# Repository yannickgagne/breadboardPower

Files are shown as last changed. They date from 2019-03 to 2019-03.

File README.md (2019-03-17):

# breadboardPower
Breadboard Power Supply

Simple breadboard power supply with 3.3V, 5V and 12V ouput.

Can provide two different voltage at the same time to different rails.

I know it could have been way smaller with more SMD components but I wanted to use what I had on hand.

https://oshpark.com/shared_projects/d1cXCggO

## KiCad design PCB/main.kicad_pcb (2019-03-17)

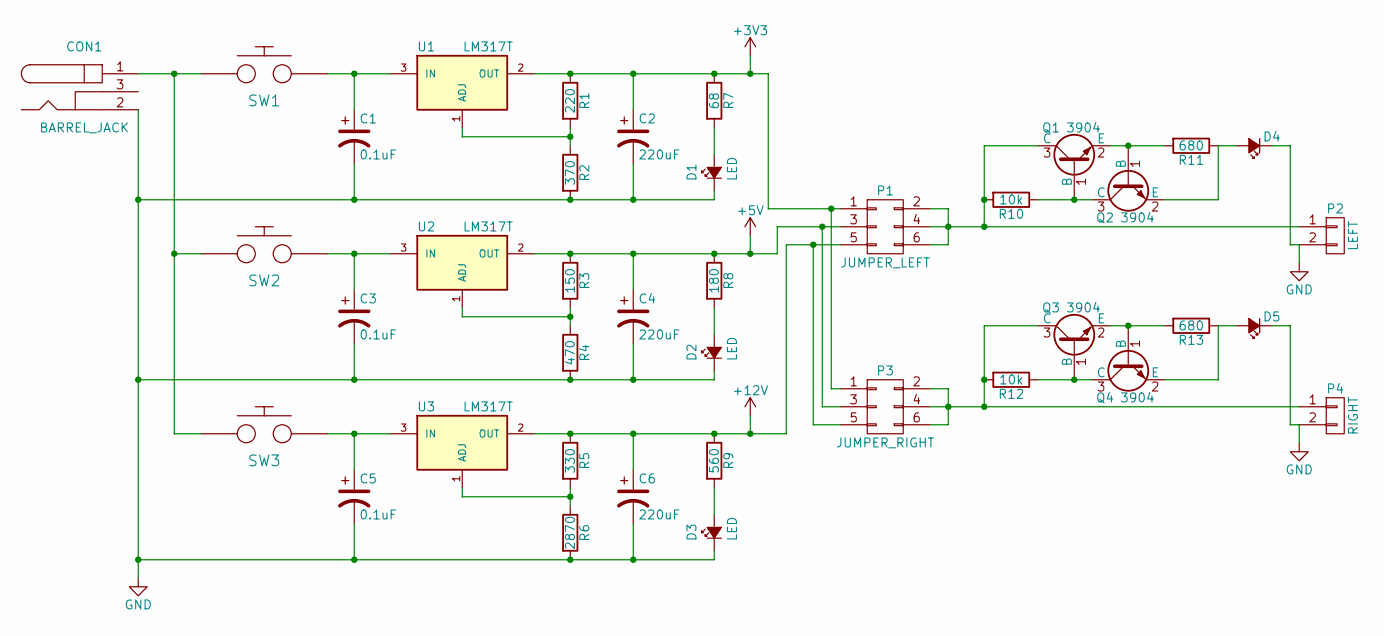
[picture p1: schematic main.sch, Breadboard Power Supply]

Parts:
C1, C3, C5: 0.1uF; C_Radial_D5_L11_P2
C2, C4, C6: 220uF; C_Radial_D6.3_L11.2_P2.5
CON1: BARREL_JACK; BARREL_JACK2
D1, D2, D3: LED; LED_0805
D4, D5: Led_Small; LED_0805
P1: JUMPER_LEFT; Pin_Header_Straight_2x03
P2: LEFT; Pin_Header_Straight_1x02
P3: JUMPER_RIGHT; Pin_Header_Straight_2x03
P4: RIGHT; Pin_Header_Straight_1x02
Q1, Q2, Q3, Q4: 3904; SOT-23
R1: 220; Resistor_Horizontal_RM7mm
R2: 370; Resistor_Horizontal_RM7mm
R3: 150; Resistor_Horizontal_RM7mm
R4: 470; Resistor_Horizontal_RM7mm
R5: 330; Resistor_Horizontal_RM7mm
R6: 2870; Resistor_Horizontal_RM7mm
R7: 68; Resistor_Horizontal_RM7mm
R8: 180; Resistor_Horizontal_RM7mm
R9: 560; Resistor_Horizontal_RM7mm
R10, R12: 10k; Resistor_Horizontal_RM7mm
R11, R13: 680; Resistor_Horizontal_RM7mm
SW1, SW2, SW3: 12x12_PUSHBUTTON_SPST
U1, U2, U3: LM317T; TO-220

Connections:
+3V3: C2.1, P1.1, P3.1, R1.1, R7.1, U1.2 (OUT)
+5V: C4.1, P1.3, P3.3, R3.1, R8.1, U2.2 (OUT)
+12V: C6.1, P1.5, P3.5, R5.1, R9.1, U3.2 (OUT)
GND: C1.2, C2.2, C3.2, C4.2, C5.2, C6.2, CON1.2, D1.1 (K), D2.1 (K), D3.1 (K), D4.1 (K), D5.1 (K), P2.2, P4.2, R2.2, R4.2, R6.2
unnamed: C1.1, SW1.2, U1.3 (IN)
unnamed: C3.1, SW2.2, U2.3 (IN)
unnamed: C5.1, SW3.2, U3.3 (IN)
unnamed: CON1.1, SW1.1, SW2.1, SW3.1
unnamed: D1.2 (A), R7.2
unnamed: D2.2 (A), R8.2
unnamed: D3.2 (A), R9.2
unnamed: D4.2 (A), Q2.2 (E), R11.1
unnamed: D5.2 (A), Q4.2 (E), R13.1
unnamed: P1.2, P1.4, P1.6, P2.1, Q1.3 (C), R10.2
unnamed: P3.2, P3.4, P3.6, P4.1, Q3.3 (C), R12.2
unnamed: Q1.1 (B), Q2.3 (C), R10.1
unnamed: Q1.2 (E), Q2.1 (B), R11.2
unnamed: Q3.1 (B), Q4.3 (C), R12.1
unnamed: Q3.2 (E), Q4.1 (B), R13.2
unnamed: R1.2, R2.1, U1.1 (ADJ)
unnamed: R3.2, R4.1, U2.1 (ADJ)
unnamed: R5.2, R6.1, U3.1 (ADJ)

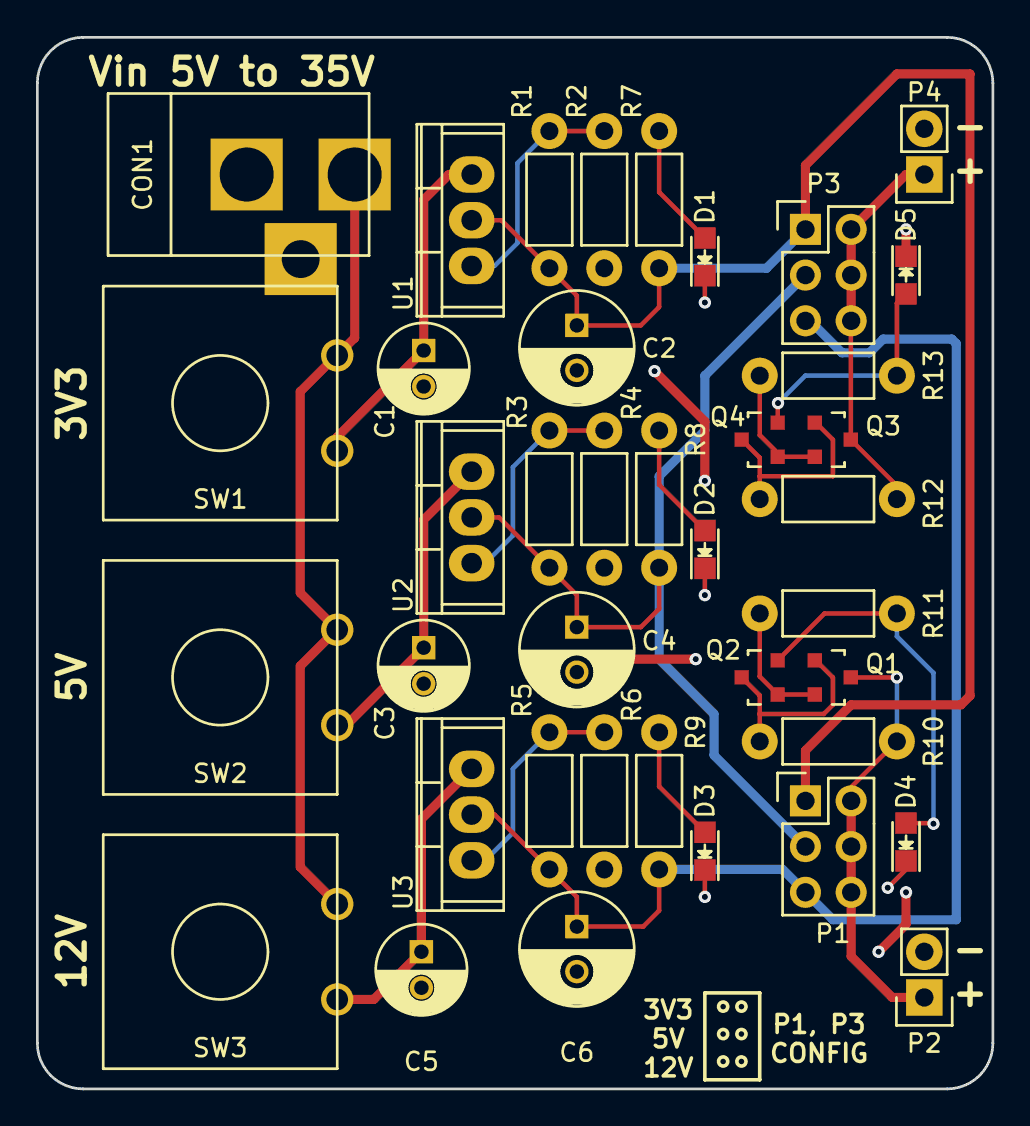
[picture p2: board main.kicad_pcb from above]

Board: 2 copper layers, 53.1 x 58.4 mm, 39 parts (0 on the bottom side), 22 nets.

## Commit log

2016-04-14 led output circuit
    [main.sch]
2016-04-15 begin pcb layout
    [main.sch]
2016-04-15 before traces
    [main.kicad_pcb]
2016-04-16 traces again
    [main.kicad_pcb]
2016-04-17 edge cuts and oshpark settings
    [main.kicad_pcb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]
2016-04-18 real switches and oshpark test
    [main-B.Cu.gbl, main-B.Mask.gbs, main-B.SilkS.gbo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]
2016-04-18 pcb powa!
    [main.kicad_pcb]
2016-04-19 smaller pcb
    [main-B.Cu.gbl, main-B.Mask.gbs, main-B.SilkS.gbo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]
2016-04-19 edge cut fix
    [main.kicad_pcb]
2016-04-19 output pins
    [main.kicad_pcb]
2016-04-19 added to top silk screen
    [main.kicad_pcb]
2016-04-20 fat holes for barrel jack
    [main.kicad_pcb, main.sch]
2016-04-25 hopefully last pcb layout
    [main-B.Cu.gbl, main-B.Mask.gbs, main-B.SilkS.gbo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]
2016-04-26 battery doc
2016-04-27 barrel jack footprint tuning
    [main-B.Cu.gbl, main-B.Mask.gbs, main-B.SilkS.gbo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]
2016-04-28 submitted to oshpark :anguished:
    praying for a working PCB!!!
    [main-B.Cu.gbl, main-B.Mask.gbs, main-B.SilkS.gbo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]
2016-05-18 Some pads hole size modification.
    [main-B.Cu.gbl, main-B.Mask.gbs, main-B.SilkS.gbo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]
2016-05-19 added jumper for disconnected ground plane section
    [main-B.Cu.gbl, main-B.Mask.gbs, main-B.SilkS.gbo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]
2019-03-17 Confirmed all v0.2 mods
    [main-B.Cu.gbl, main-B.Mask.gbs, main-B.SilkS.gbo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]
